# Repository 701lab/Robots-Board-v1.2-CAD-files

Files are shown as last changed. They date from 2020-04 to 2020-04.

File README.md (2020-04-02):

## What is Robots board v1.2?
 
**Robots board v1.2** is a cost affective board to implement small differential drive robots, for example, balancing robot. It uses _stm32g071cbu_ MCU, _DRV8848_ motor driver to control two small BDC motors, _ICM-20600_ 3-axis gyroscope and accelerometer, and _NRF24l01+_ as a radio module. Board support motors with incremental encoders and has a connector for UART communication.

## This repo contains
Autodesk Eagle CAD files for robots board v1.2 with schematics and PCB for a single board and PCB files for a pannel of 4 boards with 100x96mm (so it can be ordered as a pannel from chines manufacturers for a small price).

Open source **setup software for the board** can be found [here](https://github.com/701lab/rbv1.2-implementation).

### 3D model of the pannel of boards

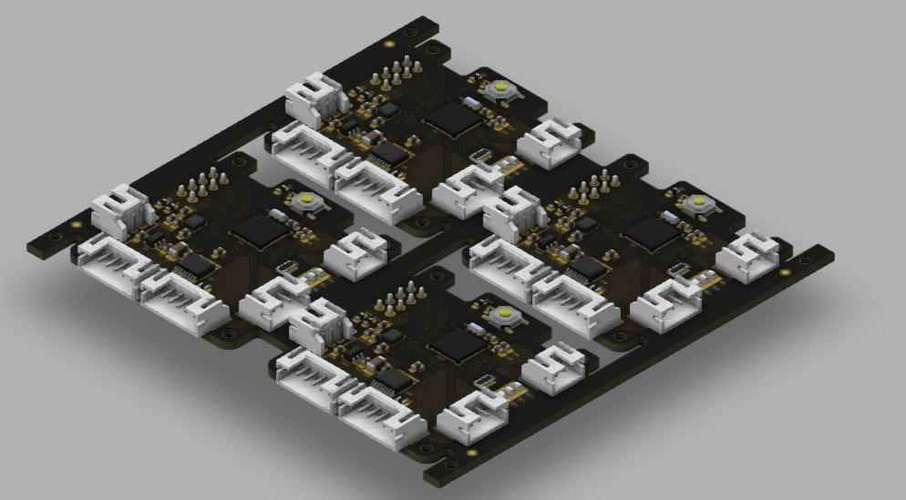
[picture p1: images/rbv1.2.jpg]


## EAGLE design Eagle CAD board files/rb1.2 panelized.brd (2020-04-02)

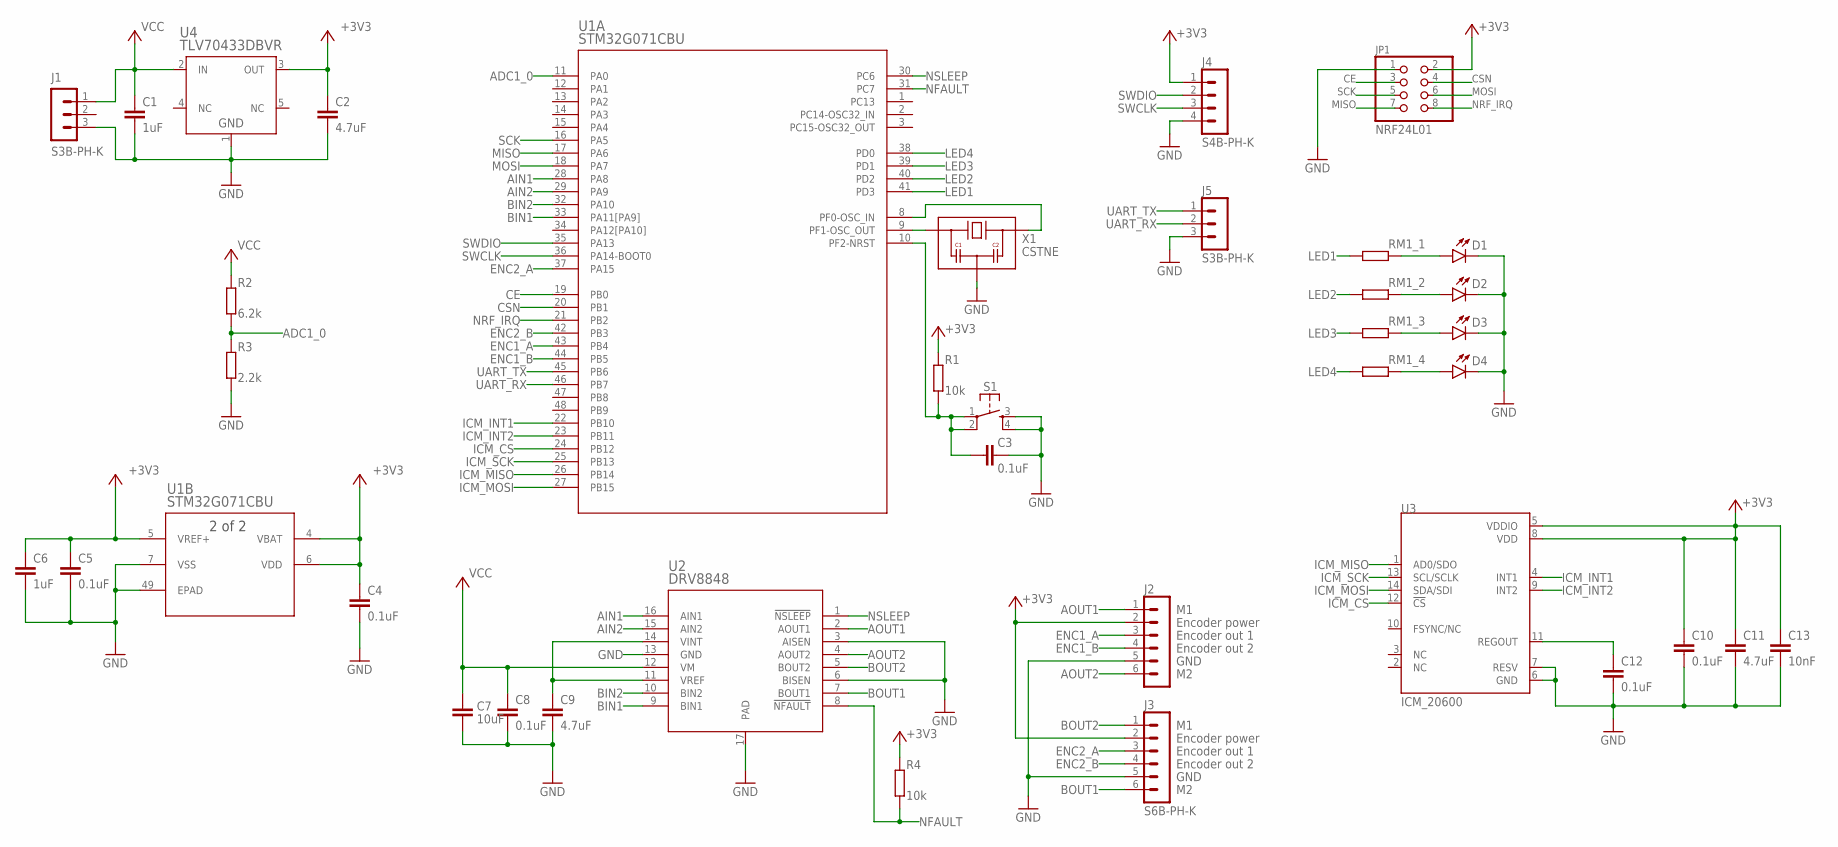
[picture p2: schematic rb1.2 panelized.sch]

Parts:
C1, C6: 1uF; C0603K
C2, C9, C11: 4.7uF; C0603K
C3: 0.1uF; C0402K
C4, C5, C8, C10, C12: 0.1uF; C0603K
C7: 10uF; C1206K
C13: 10nF; C0603K
D1, D2, D3, D4: LED0805; LED-0805
J1, J5: S3B-PH-K
J2, J3: S6B-PH-K
J4: S4B-PH-K
JP1: NRF24L01; 2X04
R1, R4: 10k; R0603
R2: 6.2k; R0603
R3: 2.2k; R0603
RM1: RES_ARRAY; 0603-ARC
S1: MOMENTARY-SWITCH-SPST-2-[SMD-5.2MM]; TACTILE_SWITCH_SMD_5.2MM
U1: STM32G071CBU; UFQFPN48-7X7MM
U2: DRV8848; HTSSOP
U3: ICM_20600; 14_PIN_LGA
U4: TLV70433DBVR; SOT-23-5
X1: CSTNE; MURATA_SMD_3P

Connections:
+3V3: C2.1, C4.1, C5.1, C6.1, C10.1, C11.1, C13.1, J2.2, J3.2, J4.1, JP1.2, R1.2, R4.2, U1.4 (VBAT), U1.5 (VREF+), U1.6 (VDD), U3.5 (VDDIO), U3.8 (VDD), U4.3 (OUT)
ADC1_0: R2.1, R3.2, U1.11 (PA0)
AIN1: U1.28 (PA8), U2.16 (AIN1)
AIN2: U1.29 (PA9), U2.15 (AIN2)
AOUT1: J2.1, U2.2 (AOUT1)
AOUT2: J2.6, U2.4 (AOUT2)
BIN1: U1.33 (PA11[PA9]), U2.9 (BIN1)
BIN2: U1.32 (PA10), U2.10 (BIN2)
BOUT1: J3.6, U2.7 (BOUT1)
BOUT2: J3.1, U2.5 (BOUT2)
CE: JP1.3, U1.19 (PB0)
CSN: JP1.4, U1.20 (PB1)
ENC1_A: J2.3, U1.43 (PB4)
ENC1_B: J2.4, U1.44 (PB5)
ENC2_A: J3.3, U1.37 (PA15)
ENC2_B: J3.4, U1.42 (PB3)
GND: C1.2, C2.2, C3.1, C4.2, C5.2, C6.2, C7.2, C8.2, C9.2, C10.2, C11.2, C12.2, C13.2, D1.- (C), D2.- (C), D3.- (C), D4.- (C), J1.3, J2.5, J3.5, J4.4, J5.3, JP1.1, R3.1, S1.3, S1.4, U1.7 (VSS), U1.49 (EPAD), U2.3 (AISEN), U2.6 (BISEN), U2.13 (GND), U2.17 (PAD), U3.6 (GND), U3.7 (RESV), U4.1 (GND), X1.2 (GND)
ICM_CS: U1.24 (PB12), U3.12 (!CS)
ICM_INT1: U1.22 (PB10), U3.4 (INT1)
ICM_INT2: U1.23 (PB11), U3.9 (INT2)
ICM_MISO: U1.26 (PB14), U3.1 (AD0/SDO)
ICM_MOSI: U1.27 (PB15), U3.14 (SDA/SDI)
ICM_SCK: U1.25 (PB13), U3.13 (SCL/SCLK)
LED1: RM1.1, U1.41 (PD3)
LED2: RM1.2 (1), U1.40 (PD2)
LED3: RM1.3 (1), U1.39 (PD1)
LED4: RM1.4 (1), U1.38 (PD0)
MISO: JP1.7, U1.17 (PA6)
MOSI: JP1.6, U1.18 (PA7)
unnamed: U1.8 (PF0-OSC_IN), X1.3 (OUT)
unnamed: U1.9 (PF1-OSC_OUT), X1.1 (IN)
unnamed: D4.+ (A), RM1.5 (2)
unnamed: D3.+ (A), RM1.6 (2)
unnamed: D2.+ (A), RM1.7 (2)
unnamed: D1.+ (A), RM1.8 (2)
NFAULT: R4.1, U1.31 (PC7), U2.8 (!NFAULT)
NRF_IRQ: JP1.8, U1.21 (PB2)
NSLEEP: U1.30 (PC6), U2.1 (!NSLEEP)
REG: C12.1, U3.11 (REGOUT)
RESET: C3.2, R1.1, S1.1, S1.2, U1.10 (PF2-NRST)
SCK: JP1.5, U1.16 (PA5)
SWCLK: J4.3, U1.36 (PA14-BOOT0)
SWDIO: J4.2, U1.35 (PA13)
UART_RX: J5.2, U1.46 (PB7)
UART_TX: J5.1, U1.45 (PB6)
VCC: C1.1, C7.1, C8.1, J1.1, R2.2, U2.12 (VM), U4.2 (IN)
VREF: C9.1, U2.11 (VREF), U2.14 (VINT)

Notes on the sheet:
GND
Encoder power
Encoder out 1
Encoder out 2

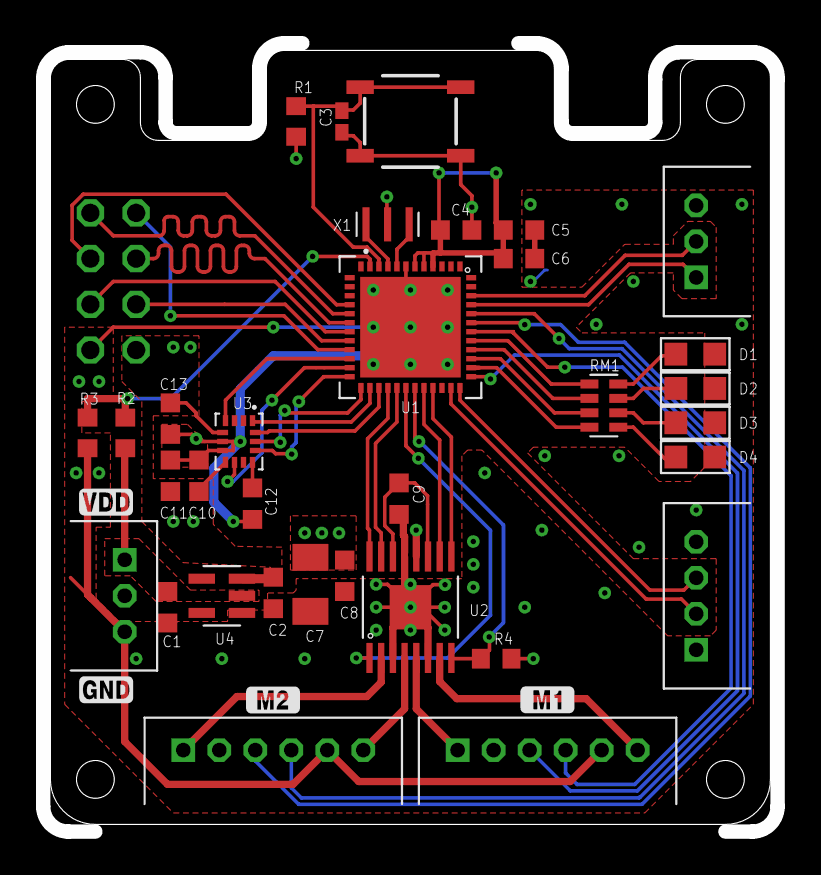
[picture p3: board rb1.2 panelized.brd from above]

Board: 2 copper layers, 40.0 x 43.0 mm, 34 parts (1 on the bottom side), 47 nets.

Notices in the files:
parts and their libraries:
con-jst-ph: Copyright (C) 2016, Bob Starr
